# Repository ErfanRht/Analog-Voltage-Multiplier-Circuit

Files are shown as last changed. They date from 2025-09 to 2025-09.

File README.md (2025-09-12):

# Analog Voltage Multiplier Circuit

### Final Project for the Electrical Circuits I Lab at Sharif University of Technology

This repository documents the design, simulation, and physical implementation of an analog voltage multiplier circuit. The project was completed as the final project for the Electrical Circuits I (EC1) course, under the supervision of Dr. Mostafa Zarghani. The circuit takes two analog voltage signals as input and produces an output voltage proportional to their product, using fundamental electronic components.

## Goals
The primary goal of this project is to build a functional analog multiplier using op-amps, diodes, and resistors. The design leverages the non-linear current-voltage characteristic of diodes to perform mathematical operations purely in the analog domain. The entire process, from theoretical design and software simulation to PCB layout and final assembly, is documented here.

### Key Specifications
* **Functionality**: Multiplies two analog input signals.
* **Input Voltage Range**: 1V to 2V.
* **Operating Frequency**: 0 to 200 Hz.
* **Power Supply**: Symmetrical ±12V DC.
* **Core Technology**: Op-Amp based logarithmic, summing, and anti-logarithmic amplifiers.
* **Implementation**: Simulated in **LTspice**, designed in **Altium Designer**, and fabricated as a physical PCB.

## Principle of Operation

The circuit's operation is based on a fundamental mathematical principle: **multiplication can be achieved by adding logarithms**.

$$ V_{out} \propto V_{in1} \times V_{in2} $$

This relationship can be transformed into the logarithmic domain:

$$ \ln(V_{out}) = \ln(V_{in1}) + \ln(V_{in2}) + C $$

The circuit implements this principle in three main stages:

1.  **Logarithmic Amplifiers**: The first stage consists of two logarithmic amplifiers, one for each input signal ($V_{in1}$ and $V_{in2}$). An op-amp with a diode in its negative feedback loop is used. The diode's exponential I-V relationship ($I_D \approx I_S e^{V_D / (n V_T)}$) results in an output voltage that is proportional to the natural logarithm of the input voltage.

2.  **Summing Amplifier**: The outputs from the two logarithmic amplifiers are fed into a summing (or adder) circuit. This op-amp configuration adds the two logarithmic signals together, effectively performing the `$\ln(V_{in1}) + \ln(V_{in2})$` operation.

3.  **Exponential (Anti-Log) Amplifier**: The final stage performs the inverse operation. An anti-logarithmic amplifier, which has a diode at its input and a resistor in the feedback loop, takes the summed logarithmic signal and produces an output that is proportional to the exponential of its input. This converts the sum of logarithms back into a product, yielding the final multiplied output signal.

## Implementation Workflow

### 1. Simulation in LTspice
The circuit was first designed and simulated in LTspice to verify its theoretical operation. The simulation confirmed that the circuit correctly multiplies the two sinusoidal input signals and operates as expected within the required frequency and voltage ranges.

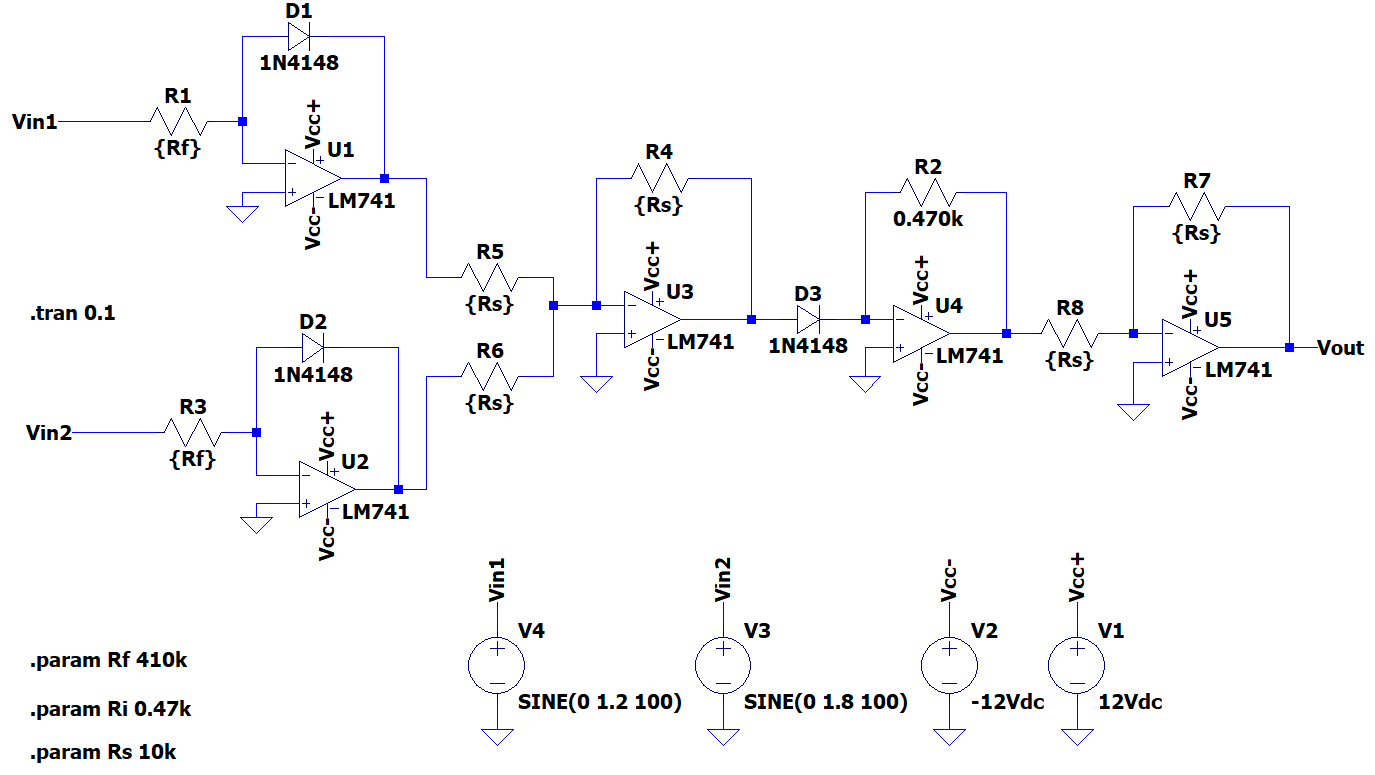
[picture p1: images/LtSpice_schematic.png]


### Waveform Analysis
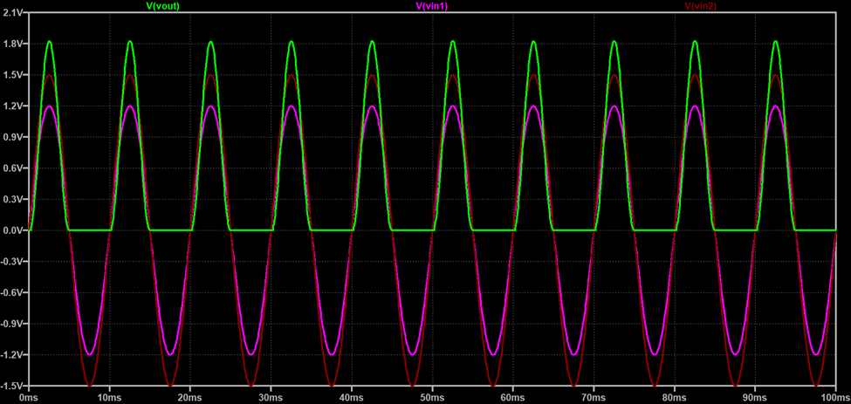
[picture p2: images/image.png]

Simulation results showing the two input sinusoids (magenta and red) and the multiplied output signal (green). The output amplitude (1.834V) closely matches the expected theoretical value (1.8V) with a minimal error of 1.9%.

### Frequency Response
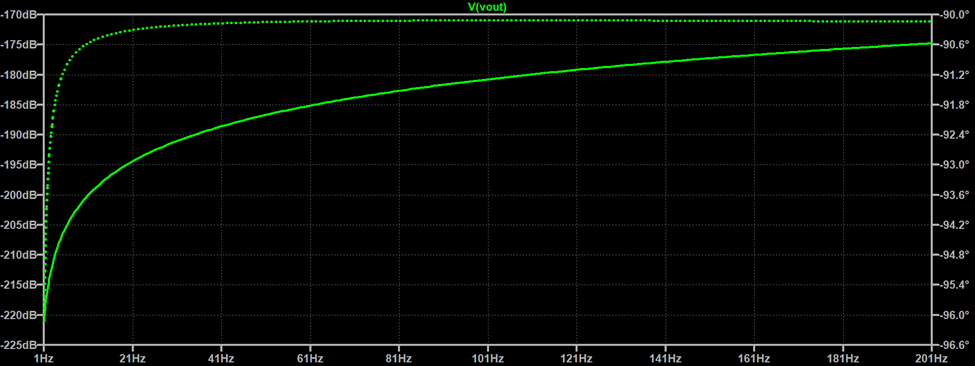
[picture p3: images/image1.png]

The frequency response was analyzed to ensure the circuit performs reliably across its specified operating range. The simulation shows that the circuit's gain is stable and consistent from 0 Hz to 200 Hz, which is ideal for the project's requirements.
Frequency response of the multiplier circuit, confirming stable operation within the 0-200 Hz range.

### Accuracy Analysis
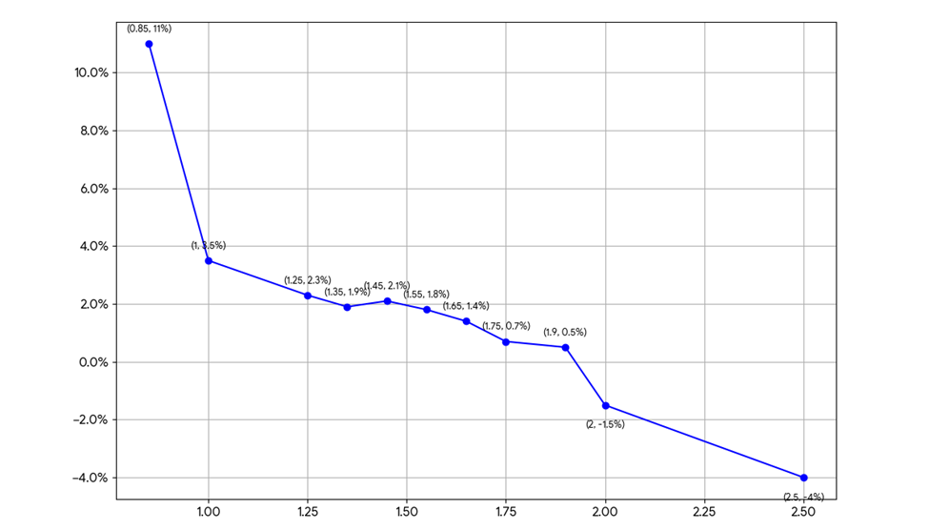
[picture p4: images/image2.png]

The accuracy of the output was tested by varying the average amplitude of the input signals. The graph below plots the percentage error of the output voltage against the average input amplitude.
This chart shows that the circuit is most accurate within the specified input voltage range of 1V to 2V. Inside this range, the output error remains low, between +2.5% and -1.5%. Outside of these bounds, the error increases significantly, demonstrating that the circuit is optimized for its designed parameters.

### 2. PCB Design in Altium Designer
After successful simulation, the schematic was transferred to Altium Designer to create a professional printed circuit board (PCB). The layout was optimized for signal integrity and component placement within the required 6x10 cm board size.

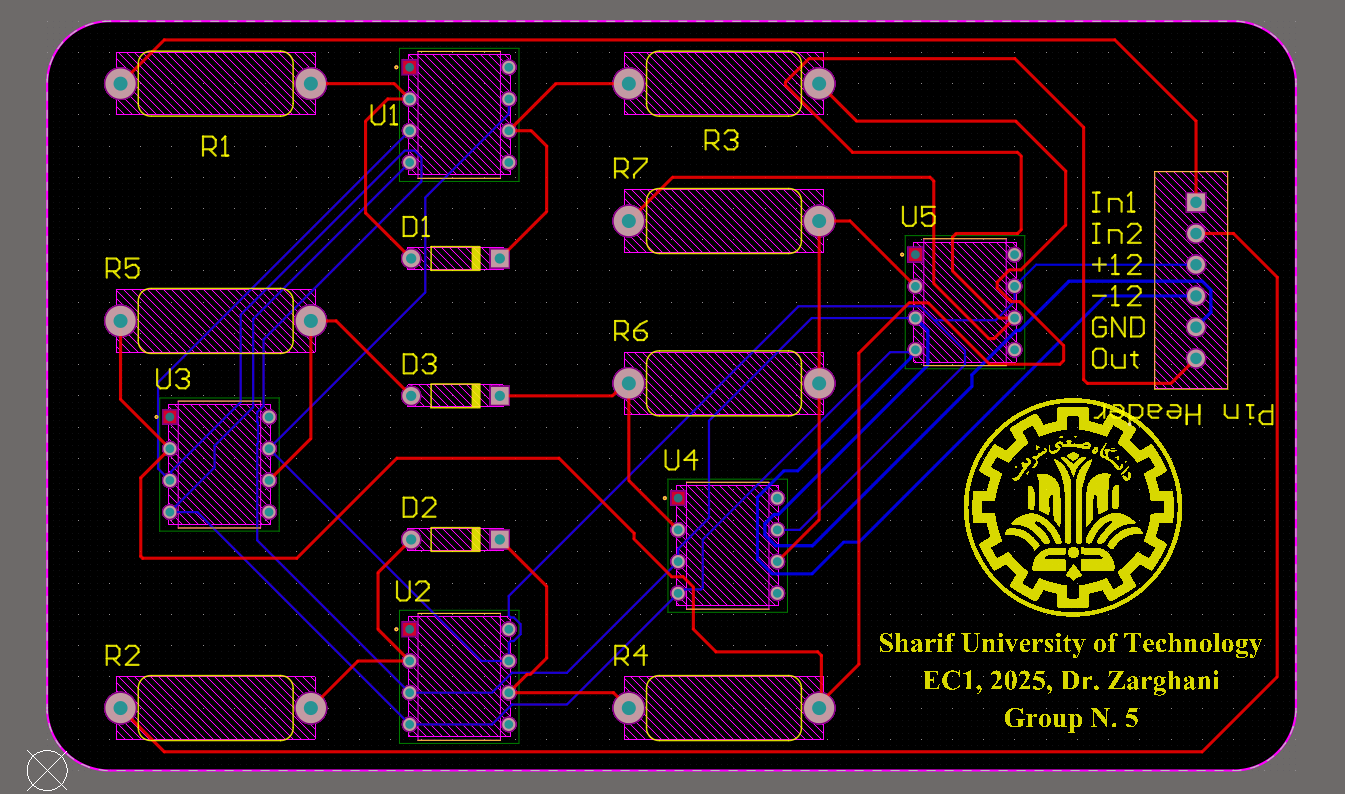
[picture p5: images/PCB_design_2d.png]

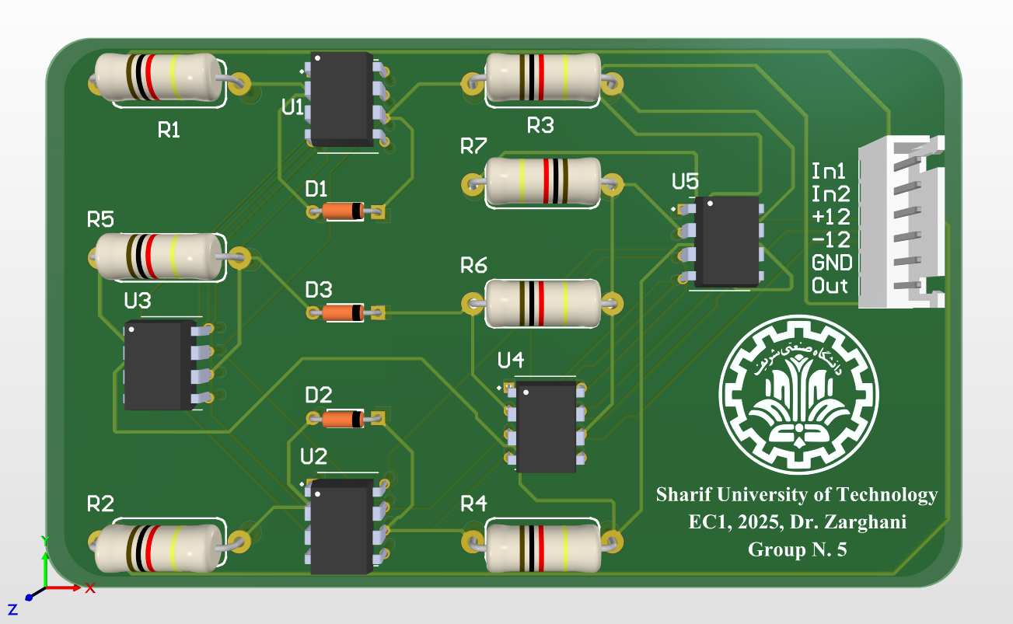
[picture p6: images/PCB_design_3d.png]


### 3. Fabrication and Assembly
The designed PCB was fabricated and assembled by hand-soldering all the through-hole components.

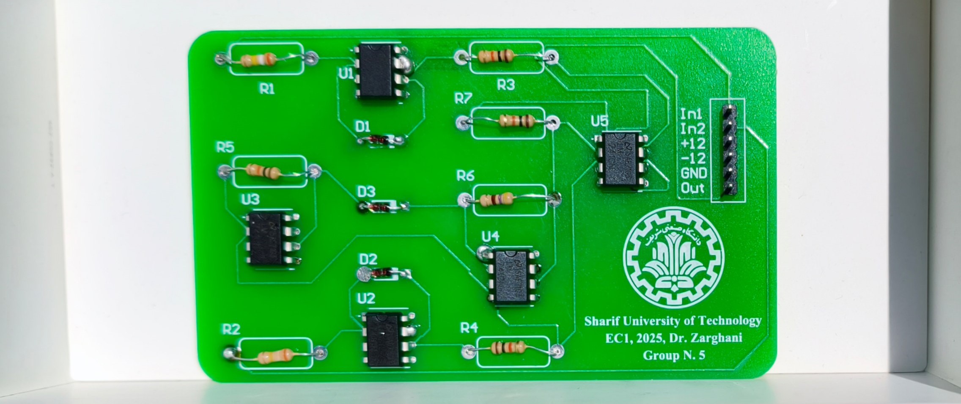
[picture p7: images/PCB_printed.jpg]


---

## Repository Contents

* `Project.asc`: The LTspice simulation file for the multiplier circuit.
* `EC1_ProjectReport_G05.pdf`: The complete project report submitted for the course (in Persian), containing detailed analysis, simulation results, and images.
* `EC_Project_Phase2_Helps.pdf`: The official project guidelines and help document from the university (in Persian).
* `README.md`: This file.

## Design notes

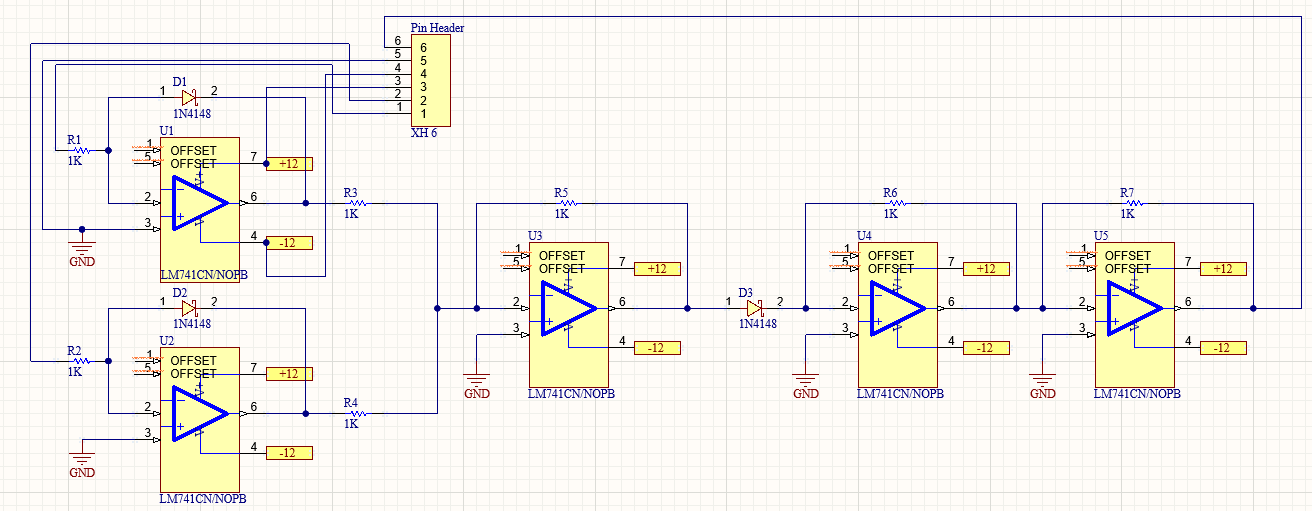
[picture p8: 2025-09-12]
images/Altium_schematic.png

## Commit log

2025-09-12 PCB files added
2025-09-20 Rename Project.asc to LtSpice - Schematic.asc
